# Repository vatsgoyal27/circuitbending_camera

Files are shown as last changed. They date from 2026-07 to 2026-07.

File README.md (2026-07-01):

# Circuit Bending Setup

ESP32-S3-DevKitC-1 based circuit bending board with camera, TFT touchscreen display, SD card, I2S speaker amp, and analog microphone.

## Hardware

- **MCU:** ESP32-S3-DevKitC-1 (N16R8)
- **Camera:** OV2640 via 24-pin 1mm pitch FPC connector (J3)
- **Display:** TFT touchscreen (J4)
- **Storage:** MicroSD card (J27, Hirose DM3AT-SF-PEJM5)
- **Speaker amp:** MAX98357A I2S class D amp (U2)
- **Microphone:** MAX4466 analog mic preamp (U4)
- **Power:** IP2312 LiPo charger (U5) + MT3608 boost converter to 5V (U1)
- **LEDs:** 3x WS2812B addressable RGB (D5, D6, D7), daisy chained
- **Bend points:** Single pin 2.54mm headers throughout (J2, J5, J10–J26 etc.)

## Pin Map (WIll be updated and corrected soon)

### Camera (OV2640 DVP 8-bit)

| Signal | GPIO |
|---|---|
| xclk | 15 |
| pclk | 13 |
| vsync | 6 |
| href | 7 |
| d2 | 11 |
| d3 | 9 |
| d4 | 8 |
| d5 | 10 |
| d6 | 12 |
| d7 | 18 |
| d8 | 17 |
| d9 | 16 |
| sda (SCCB) | 4 |
| scl (SCCB) | 5 |

> pwdn and rstb are hardwired by R7/R8/R10, no GPIO needed.
> d0 and d1 are not connected (OV2640 outputs 8-bit only).

### Shared SPI Bus (TFT + touch + SD)

| Signal | GPIO |
|---|---|
| sck | 39 |
| mosi | 40 |
| miso | 41 |
| lcdcs | 42 |
| lcdrst | 38 |
| lcddc/rs | 47 |
| t_irq | 21 |
| sdcs | 43 |
| t_cs | 44 |

### I2S Amp (MAX98357A)

| Signal | GPIO |
|---|---|
| din | 2 |
| bclk | 14 |
| lrclk | 48 |

> sd_mode and gain are hardwired via R1, not software controlled.

### Microphone (MAX4466)

| Signal | GPIO |
|---|---|
| mic | 1 |

> Must be ADC1 (GPIO1-10) — ADC2 is unreliable with WiFi active.

### LEDs (WS2812B)

| Signal | GPIO |
|---|---|
| led_data | 0 |

> D5 → D6 → D7 daisy chained. One GPIO drives all three.

## Pins Avoided and Why

| GPIO | Reason |
|---|---|
| 3, 45, 46 | Strapping pins |
| 19, 20 | Native USB D-/D+ |
| 35, 36, 37 | Internally wired to octal PSRAM on N16R8 |

## Power

- Battery: 3.7V LiPo via JST PH 2.0mm (BT1)
- Charging: IP2312 module (U5) via USB-C
- 5V rail: MT3608 boost converter (U1) from battery
- 3.3V rail: onboard ESP32-S3 regulator
- 1.2V rail: NIC5365 LDO (U6) for camera
- 2.8V rail: MIC5504 LDO (U7) for camera

## Flashing

Flash and monitor over the **native USB port** (GPIO19/20, labeled "USB" on the DevKitC-1). Do not use the UART port (labeled "UART") — GPIO43/44 are repurposed for SPI chip selects and that port will show garbage. Select **USB CDC On Boot** in your build config.

## Built in KiCad
- KiCad E.D.A. 9.0.6

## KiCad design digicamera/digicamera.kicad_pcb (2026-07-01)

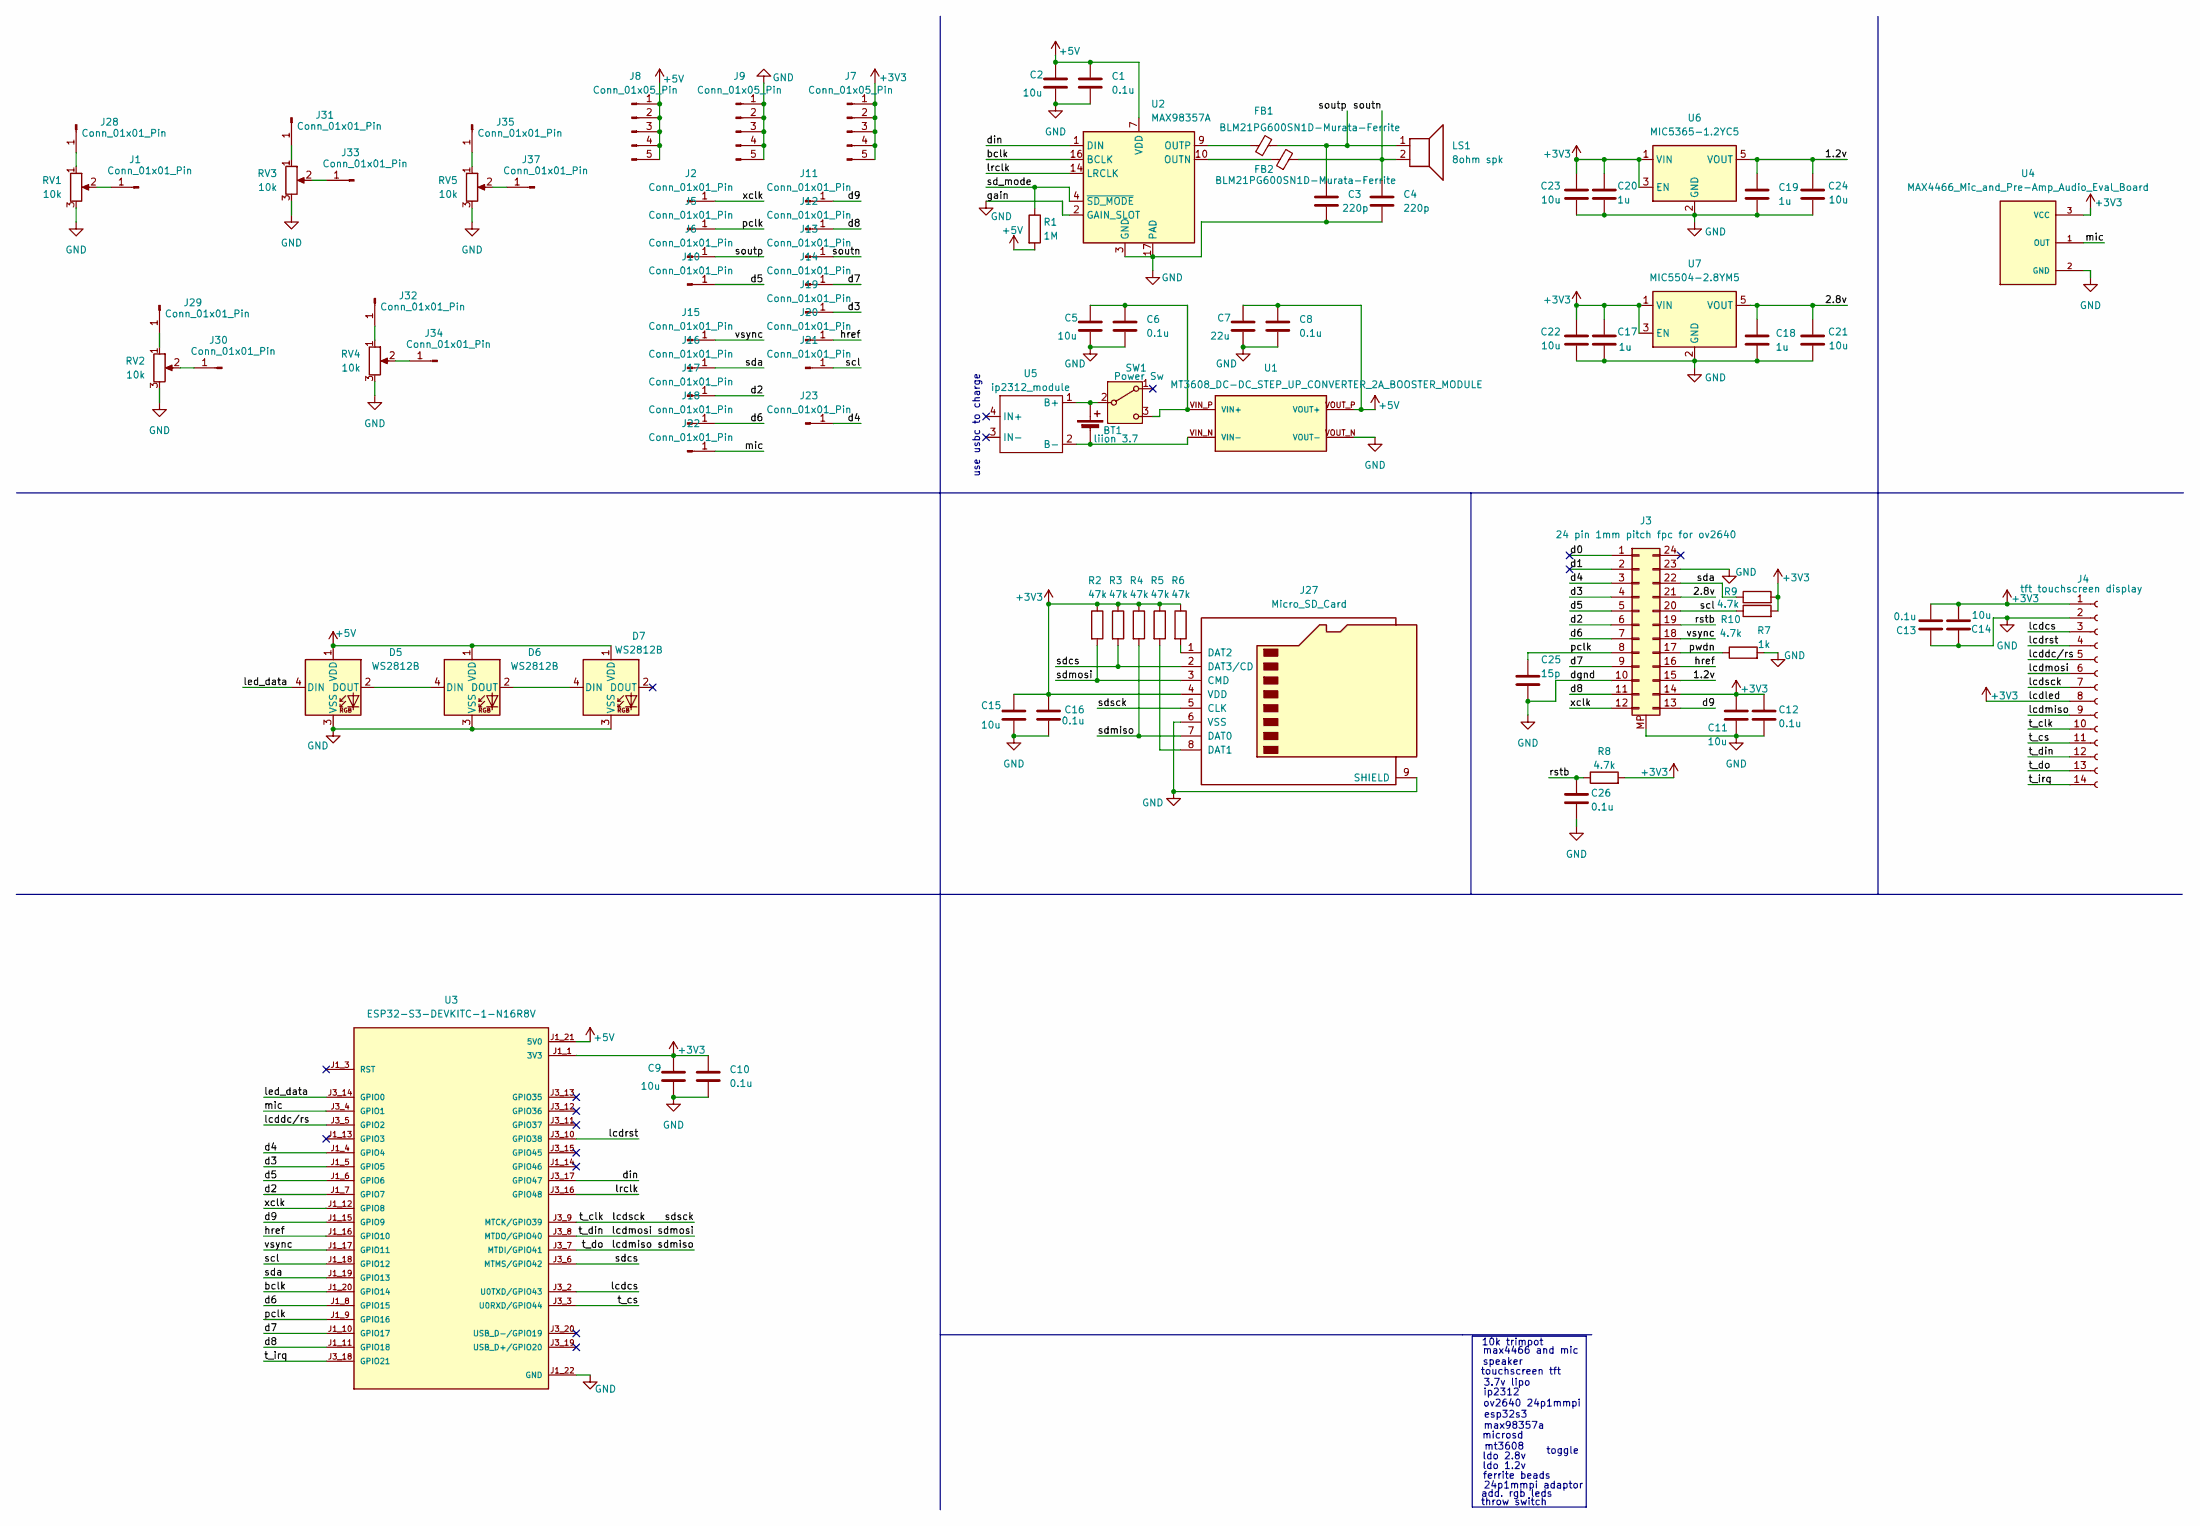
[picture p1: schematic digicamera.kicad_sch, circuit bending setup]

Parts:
BT1: liion 3.7; JST_PH_S2B-PH-K_1x02_P2.00mm_Horizontal
C1, C6, C8, C10, C12, C13, C16, C26: 0.1u; C_0805_2012Metric
C2, C5, C9, C11, C14, C15, C21, C22, C23, C24: 10u; C_0805_2012Metric
C3, C4: 220p; C_0805_2012Metric
C7: 22u; C_0805_2012Metric
C17, C18, C19, C20: 1u; C_0805_2012Metric
C25: 15p; C_0805_2012Metric
D5, D6, D7: WS2812B; LED_WS2812B_PLCC4_5.0x5.0mm_P3.2mm
FB1, FB2: BLM21PG600SN1D-Murata-Ferrite; BEADC2012X105N
J1, J2, J5, J6, J10, J11, J12, J13, J14, J15, J16, J17, J18, J19, J20, J21, J22, J23, J28, J29, J30, J31, J32, J33, J34, J35, J37: Conn_01x01_Pin; PinHeader_1x01_P2.54mm_Vertical
J3: 24 pin 1mm pitch fpc for ov2640; Molex_200528-0240_1x24-1MP_P1.00mm_Horizontal
J4: tft touchscreen display; PinHeader_1x14_P2.54mm_Vertical
J7, J8, J9: Conn_01x05_Pin; PinHeader_1x05_P2.54mm_Vertical
J27: Micro_SD_Card; microSD_HC_Hirose_DM3AT-SF-PEJM5
LS1: 8ohm spk; JST_PH_S2B-PH-K_1x02_P2.00mm_Horizontal
R1: 1M; R_0805_2012Metric
R2, R3, R4, R5, R6: 47k; R_0805_2012Metric
R7: 1k; R_0805_2012Metric
R8, R9, R10: 4.7k; R_0805_2012Metric
RV1, RV2, RV3, RV4, RV5: 10k; Potentiometer_Bourns_3386P_Vertical
SW1: Power Sw; RLS-102-F1-Toggle
U1: MT3608_DC-DC_STEP_UP_CONVERTER_2A_BOOSTER_MODULE; MODULE_MT3608_DC-DC_STEP_UP_CONVERTER_2A_BOOSTER_MODULE
U2: MAX98357A; QFN50P300X300X80-17N
U3: ESP32-S3-DEVKITC-1-N16R8V; XCVR_ESP32-S3-DEVKITC-1-N16R8V; PARTREV 1.1
U4: MAX4466_Mic_and_Pre-Amp_Audio_Eval_Board; MODULE_MAX4466_Microphone_Pre-Amp_Audio_Evaluation_Board; PARTREV 1.0
U5: ip2312_module; Untitled
U6: MIC5365-1.2YC5; SOT-353_SC-70-5
U7: MIC5504-2.8YM5; SOT-23-5

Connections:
+3V3: C9.1, C10.1, C11.1, C12.1, C13.2, C14.2, C15.1, C16.1, C17.1, C20.1, C22.1, C23.1, J3.14, J4.1, J4.8, J7.1, J7.2, J7.3, J7.4, J7.5, J27.4 (VDD), R2.1, R3.1, R4.1, R5.1, R6.1, R8.2, R9.2, R10.2, U3.J1_1 (3V3), U3.J1_2 (3V3), U4.3 (VCC), U6.1 (VIN), U6.3 (EN), U7.1 (VIN), U7.3 (EN)
+5V: C1.1, C2.1, C7.1, C8.1, D5.1 (VDD), D6.1 (VDD), D7.1 (VDD), J8.1, J8.2, J8.3, J8.4, J8.5, R1.2, U1.VOUT_P (VOUT+), U2.7 (VDD), U2.8 (VDD), U3.J1_21 (5V0)
/1.2v: C19.1, C24.1, J3.15, U6.5 (VOUT)
/2.8v: C18.1, C21.1, J3.21, U7.5 (VOUT)
/bclk: U2.16 (BCLK), U3.J1_20 (GPIO14)
/d0: J3.1
/d1: J3.2
/d2: J3.6, J17.1, U3.J1_7 (GPIO7)
/d3: J3.4, J19.1, U3.J1_5 (GPIO5)
/d4: J3.3, J23.1, U3.J1_4 (GPIO4)
/d5: J3.5, J10.1, U3.J1_6 (GPIO6)
/d6: J3.7, J18.1, U3.J1_8 (GPIO15)
/d7: J3.9, J14.1, U3.J1_10 (GPIO17)
/d8: J3.11, J12.1, U3.J1_11 (GPIO18)
/d9: J3.13, J11.1, U3.J1_15 (GPIO9)
/din: U2.1 (DIN), U3.J3_17 (GPIO47)
/href: J3.16, J20.1, U3.J1_16 (GPIO10)
/lcdcs: J4.3, U3.J3_2 (U0TXD/GPIO43)
/lcddc/rs: J4.5, U3.J3_5 (GPIO2)
/lcdmiso: J4.9, J4.13, J27.7 (DAT0), R4.2, U3.J3_7 (MTDI/GPIO41)
/lcdmosi: J4.6, J4.12, J27.3 (CMD), R2.2, U3.J3_8 (MTDO/GPIO40)
/lcdrst: J4.4, U3.J3_10 (GPIO38)
/lcdsck: J4.7, J4.10, J27.5 (CLK), U3.J3_9 (MTCK/GPIO39)
/led_data: D5.4 (DIN), U3.J3_14 (GPIO0)
/lrclk: U2.14 (LRCLK), U3.J3_16 (GPIO48)
/mic: J22.1, U3.J3_4 (GPIO1), U4.1 (OUT)
/pclk: C25.1, J3.8, J5.1, U3.J1_9 (GPIO16)
/pwdn: J3.17, R7.1
/rstb: C26.1, J3.19, R8.1
/scl: J3.20, J21.1, R10.1, U3.J1_18 (GPIO12)
/sd_mode: R1.1, U2.4 (~SD_MODE)
/sda: J3.22, J16.1, R9.1, U3.J1_19 (GPIO13)
/sdcs: J27.2 (DAT3/CD), R3.2, U3.J3_6 (MTMS/GPIO42)
/soutn: C4.1, FB2.2, J13.1, LS1.2
/soutp: C3.1, FB1.2, J6.1, LS1.1
/t_cs: J4.11, U3.J3_3 (U0RXD/GPIO44)
/t_irq: J4.14, U3.J3_18 (GPIO21)
/vsync: J3.18, J15.1, U3.J1_17 (GPIO11)
/xclk: J2.1, J3.12, U3.J1_12 (GPIO8)
GND: C1.2, C2.2, C3.2, C4.2, C5.2, C6.2, C7.2, C8.2, C9.2, C10.2, C11.2, C12.2, C13.1, C14.1, C15.2, C16.2, C17.2, C18.2, C19.2, C20.2, C21.2, C22.2, C23.2, C24.2, C25.2, C26.2, D5.3 (VSS), D6.3 (VSS), D7.3 (VSS), J3.10, J3.23, J3.MP, J4.2, J9.1, J9.2, J9.3, J9.4, J9.5, J27.6 (VSS), J27.9 (SHIELD), R7.2, RV1.3, RV2.3, RV3.3, RV4.3, RV5.3, U1.VOUT_N (VOUT-), U2.2 (GAIN_SLOT), U2.3 (GND), U2.11 (GND), U2.15 (GND), U2.17 (PAD), U3.J1_22 (GND), U3.J3_1 (GND), U3.J3_21 (GND), U3.J3_22 (GND), U4.2 (GND), U6.2 (GND), U7.2 (GND)
unnamed: BT1.1 (+), SW1.2 (B), U5.1 (B+)
unnamed: BT1.2 (-), U1.VIN_N (VIN-), U5.2 (B-)
unnamed: D5.2 (DOUT), D6.4 (DIN)
unnamed: D6.2 (DOUT), D7.4 (DIN)
unnamed: J1.1, RV1.2
unnamed: J27.8 (DAT1), R5.2
unnamed: J27.1 (DAT2), R6.2
unnamed: J28.1, RV1.1
unnamed: J29.1, RV2.1
unnamed: J30.1, RV2.2
unnamed: J31.1, RV3.1
unnamed: J32.1, RV4.1
unnamed: J33.1, RV3.2
unnamed: J34.1, RV4.2
unnamed: J35.1, RV5.1
unnamed: J37.1, RV5.2
unnamed: C5.1, C6.1, SW1.3 (C), U1.VIN_P (VIN+)
unnamed: FB2.1, U2.10 (OUTN)
unnamed: FB1.1, U2.9 (OUTP)

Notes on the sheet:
ov2640 24p1mmpi
microsd
throw switch
ldo 1.2v
use usbc to charge
ip2312
ferrite beads
toggle
mt3608
10k trimpot
3.7v lipo
speaker
max98357a
ldo 2.8v
24p1mmpi adaptor
max4466 and mic
touchscreen tft
add. rgb leds
esp32s3

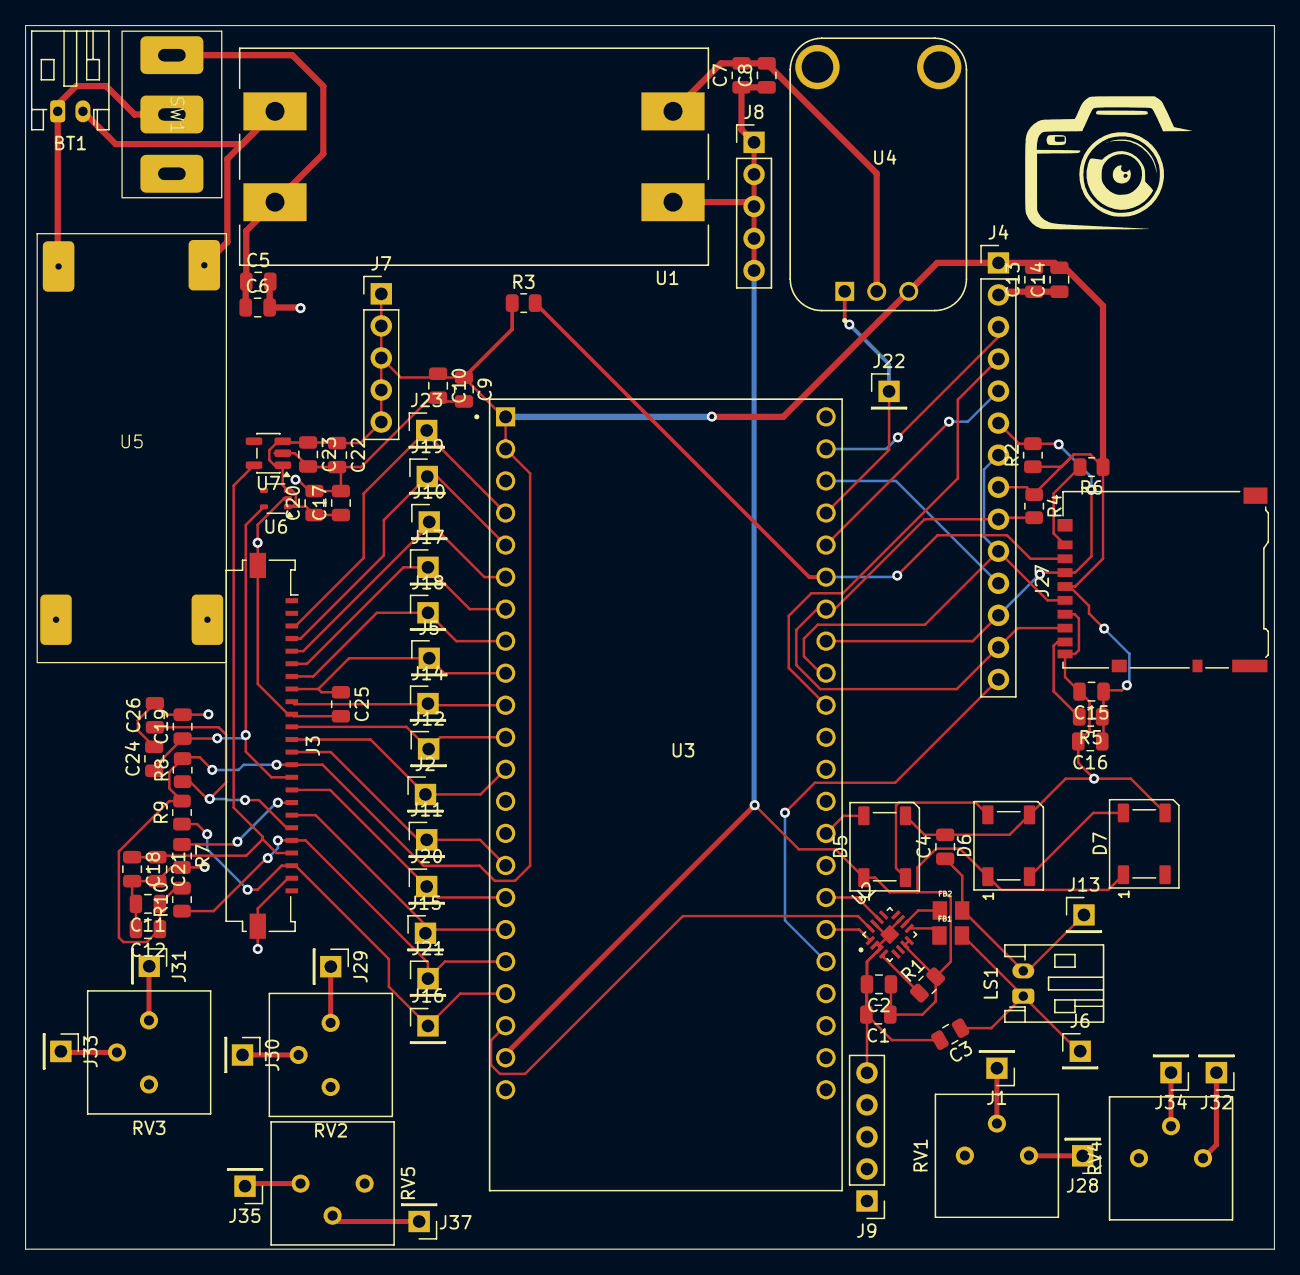
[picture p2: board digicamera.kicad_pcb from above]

Board: 2 copper layers, 99.0 x 97.0 mm, 89 parts (0 on the bottom side), 57 nets.

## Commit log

2026-06-28 kicad schematic
    in progress
    [digicamera.kicad_pcb, digicamera.kicad_sch]
2026-07-01 finished pcb v1
    [digicamera.kicad_pcb, digicamera.kicad_sch]
2026-07-01 Add README for Circuit Bending Setup
    Added detailed documentation for the Circuit Bending Setup, including hardware specifications, pin maps, power requirements, and flashing instructions.
